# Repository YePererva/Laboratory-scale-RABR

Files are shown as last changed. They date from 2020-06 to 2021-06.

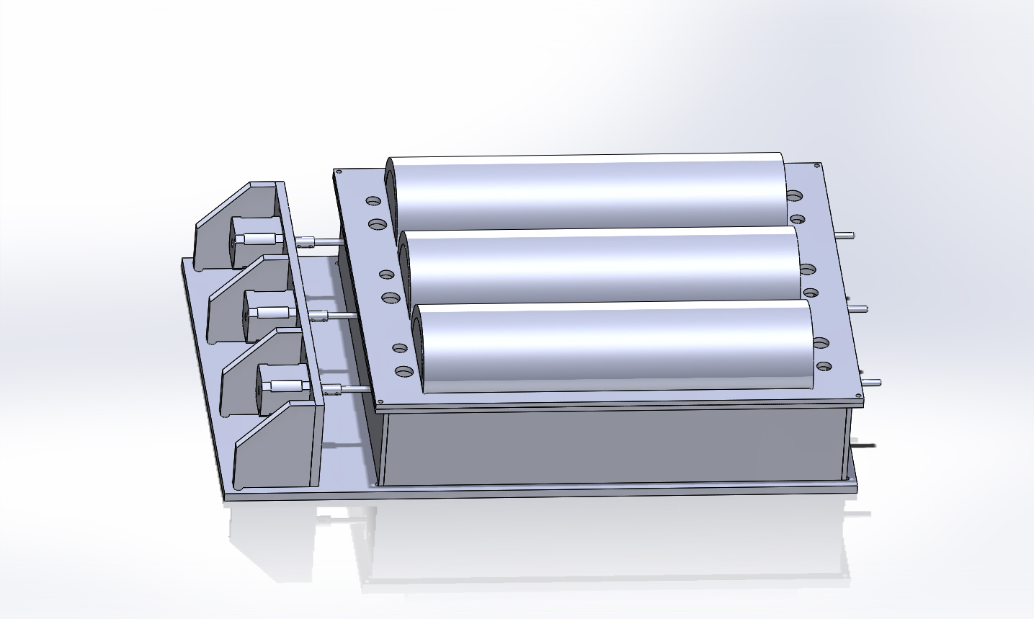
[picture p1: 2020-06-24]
images/RABR_Covered.JPG

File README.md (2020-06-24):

# Laboratory scale RABR

This repository contains some developments on laboratory-scale Rotating Algal Biofilm Reactor (RABR).
The reactor were build for one of student-projects.

# Content

Folder `electronics` contains the schematics for two designed devices:
- Motor controller for there stepper motors as shaft drives for reactor
- Environment monitor for monitoring conditions of air and light around reactor. This monitor reads:
   - Temperature, Pressure and Relative Humidity of air (with conversion to absolute humidity)
   - Total flux, Photo-synthetically Active Radiation, UV flux.

Folder `models` contains the designer reactor for running in triplicate.

Folder `images` contains CAD renders and photos taken of working reactor and equipment.

# Used tools:
- KiCad : for schematics
- SolidWorks Educational : for designing the reactor

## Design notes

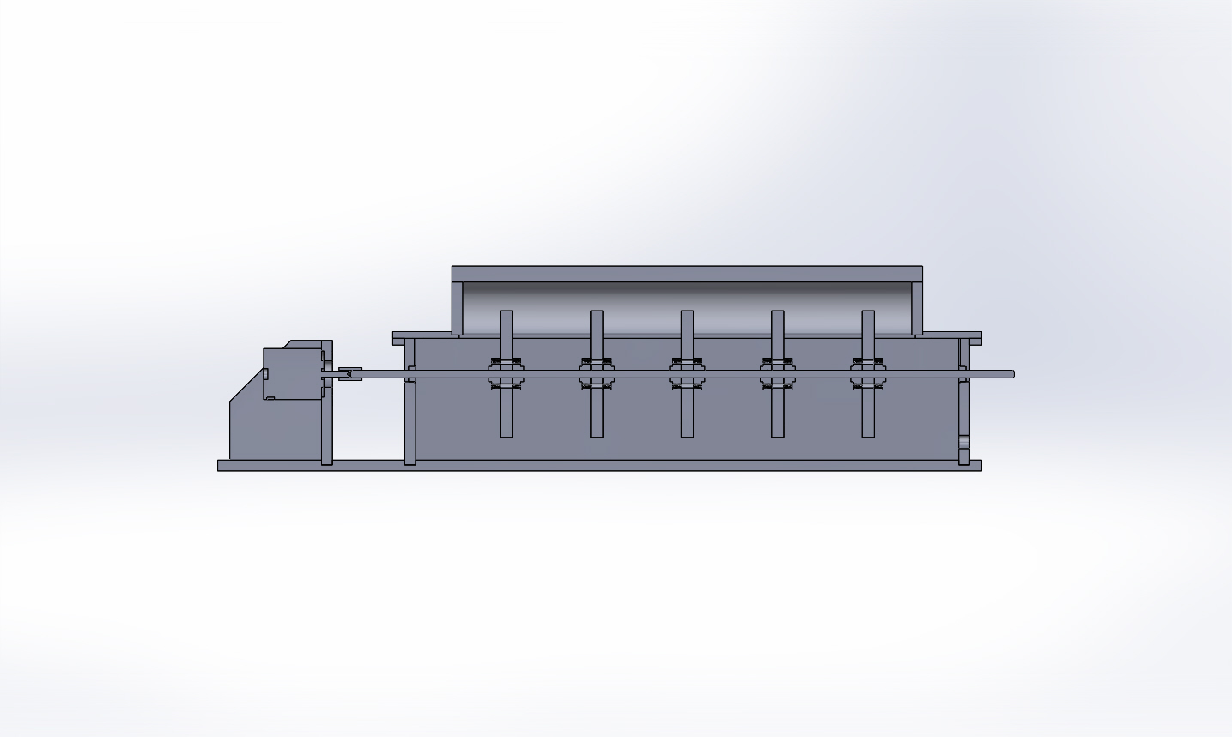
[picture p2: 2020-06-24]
images/RABR_Covered_.JPG

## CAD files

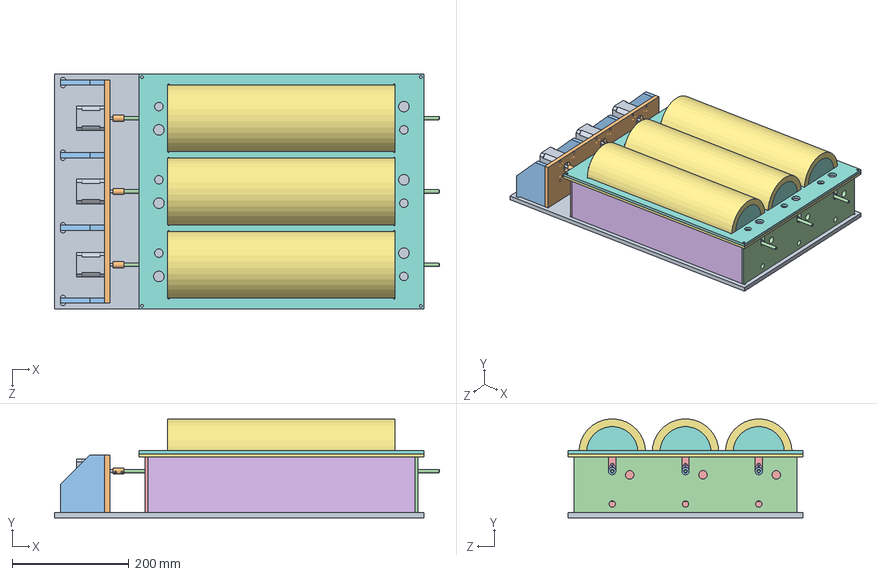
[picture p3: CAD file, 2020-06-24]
models/RABR_Covered.SLDASM
660.0 x 169.7 x 402.4 mm
bottom_plate^RABR_Covered
motor_plate^RABR_Covered
back_support^RABR_Covered x 4
outer_shaft_support^RABR_Covered
inner_shaft_support^RABR_Covered
separator^RABR_Covered x 4
bottom_lid^RABR_Covered
top_lid^RABR_Covered
NEMA17 x 3
Shaft_Coupler x 3
Bearing_immitation x 6
Shaft^RABR_Covered x 3
disk^RABR_Covered x 15
shaft_moun_hub x 30
Cover^RABR_Covered x 3
cover_side^RABR_Covered x 6

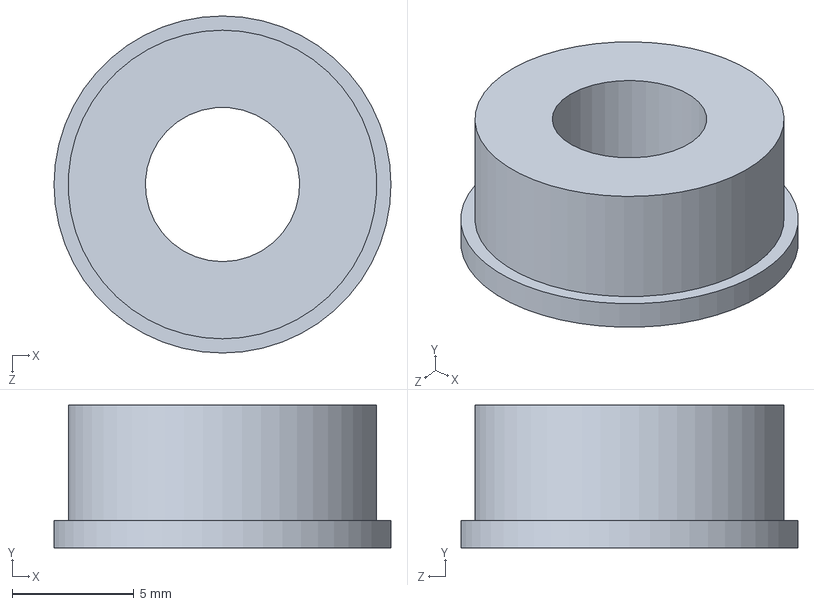
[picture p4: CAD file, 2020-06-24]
models/external_parts/Bearing_immitation.SLDPRT
13.9 x 5.87 x 13.9 mm

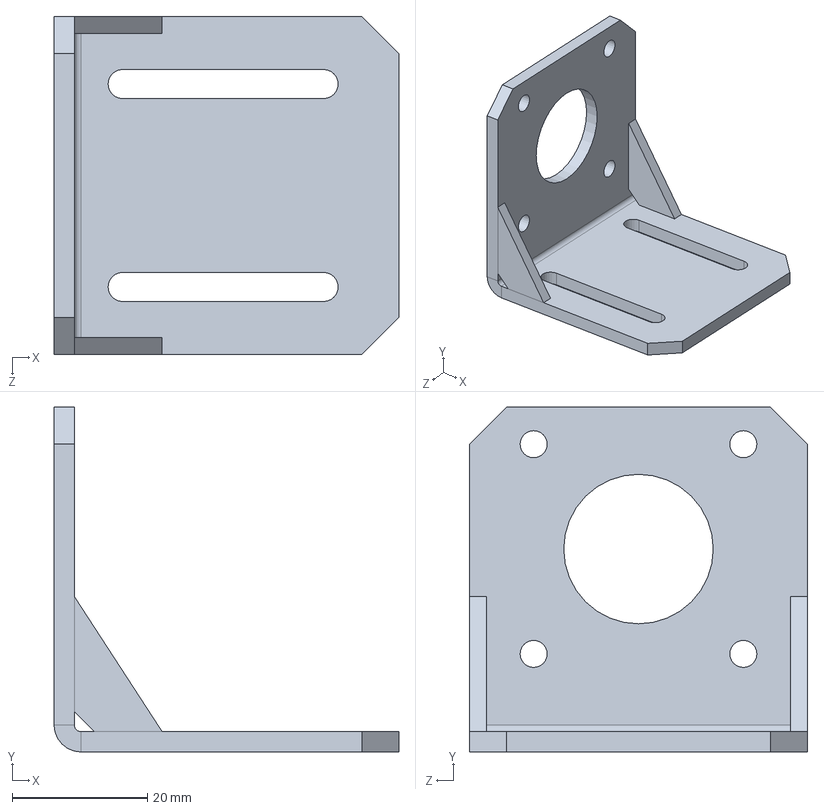
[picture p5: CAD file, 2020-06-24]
models/external_parts/NEMA17_Adaptor.SLDPRT
51.0 x 51.0 x 50.0 mm

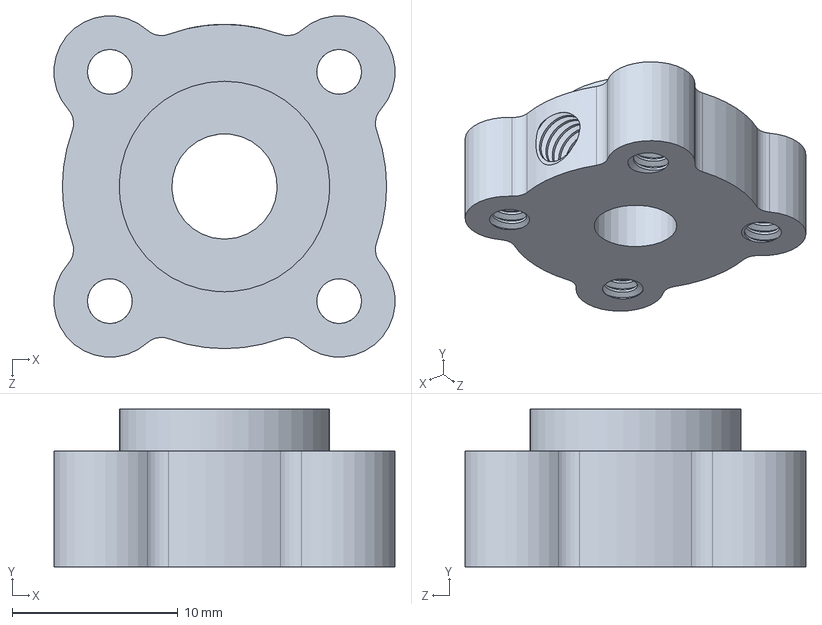
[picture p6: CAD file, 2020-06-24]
models/external_parts/shaft_moun_hub.SLDPRT
20.6 x 9.53 x 20.6 mm

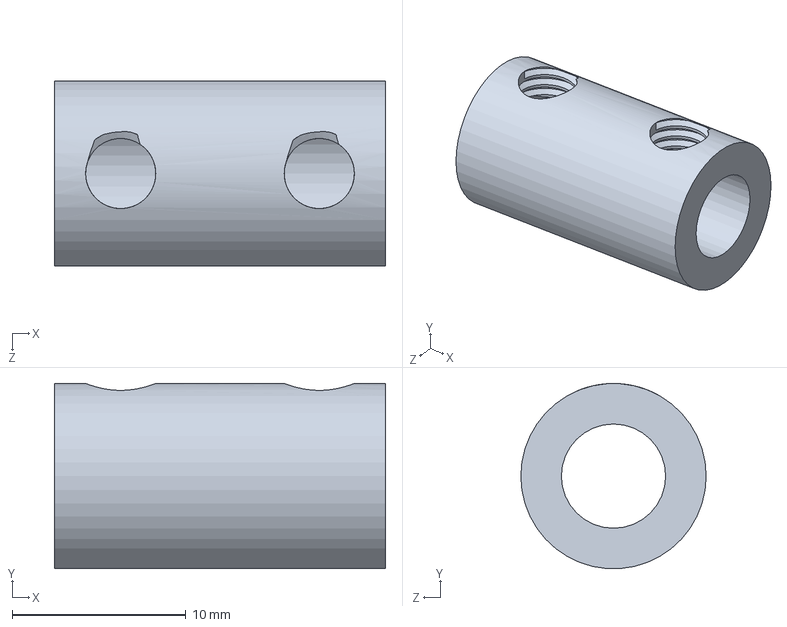
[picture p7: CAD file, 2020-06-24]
models/external_parts/Shaft_Coupler.SLDPRT
19.1 x 10.7 x 10.7 mm

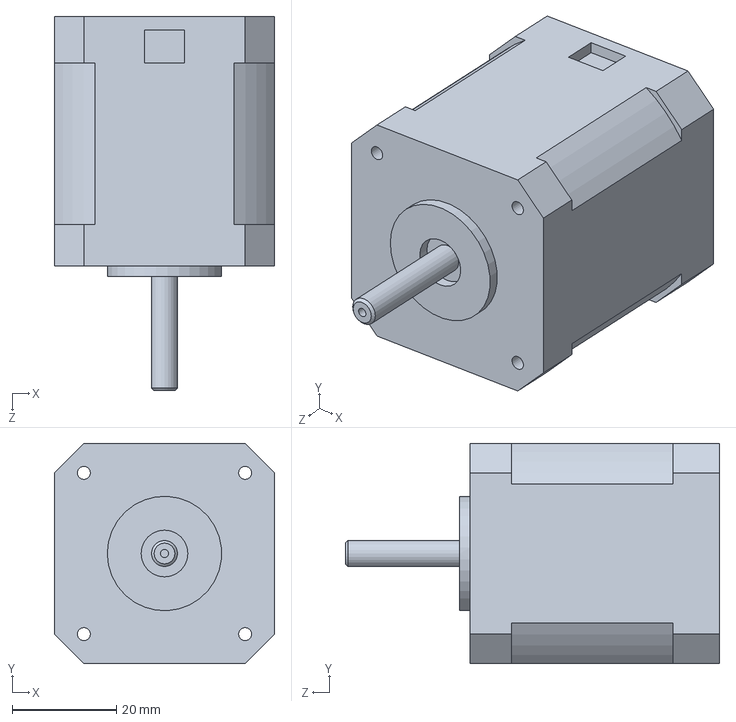
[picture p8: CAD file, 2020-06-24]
models/external_parts/NEMA17.SLDPRT
42.3 x 42.3 x 72.0 mm

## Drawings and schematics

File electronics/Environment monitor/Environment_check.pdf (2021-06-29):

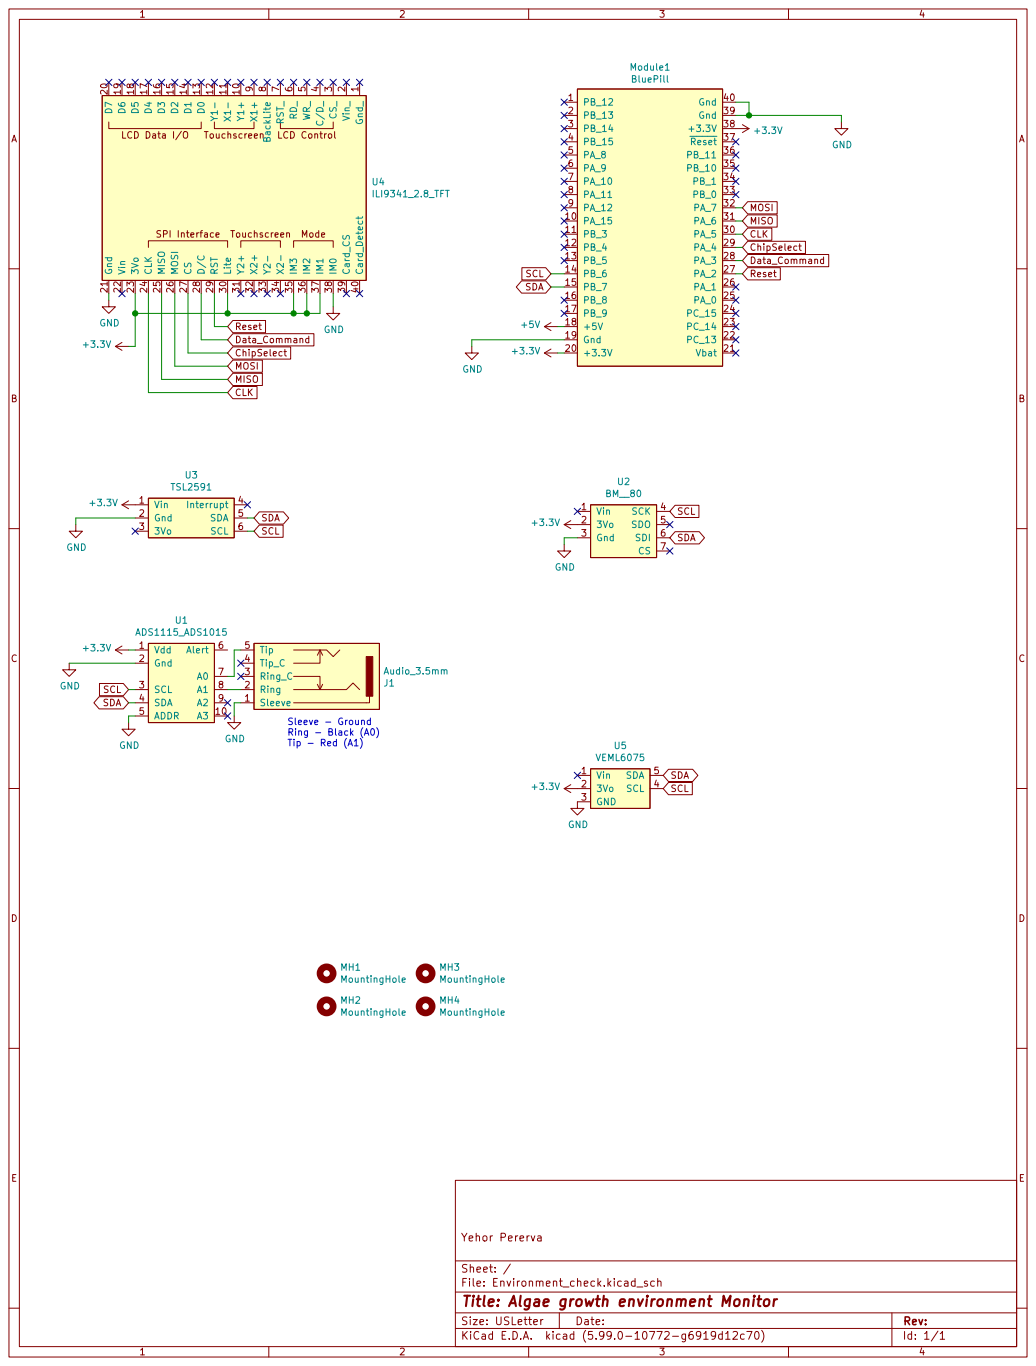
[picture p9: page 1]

2 D7 20 Gnd 21 Vin 22 3Vo 23 CLK 24 MISO 25 MOSI 26 CS 27 D/C 28 RST 29 CS_

CLK ChipSelect Data_Command MOSI Reset Sleeve - Ground Ring - Black (A0)

File: Environment_check.kicad_sch Sheet: / Yehor Pererva

Id: 1/1 Title: Algae growth environment Monitor

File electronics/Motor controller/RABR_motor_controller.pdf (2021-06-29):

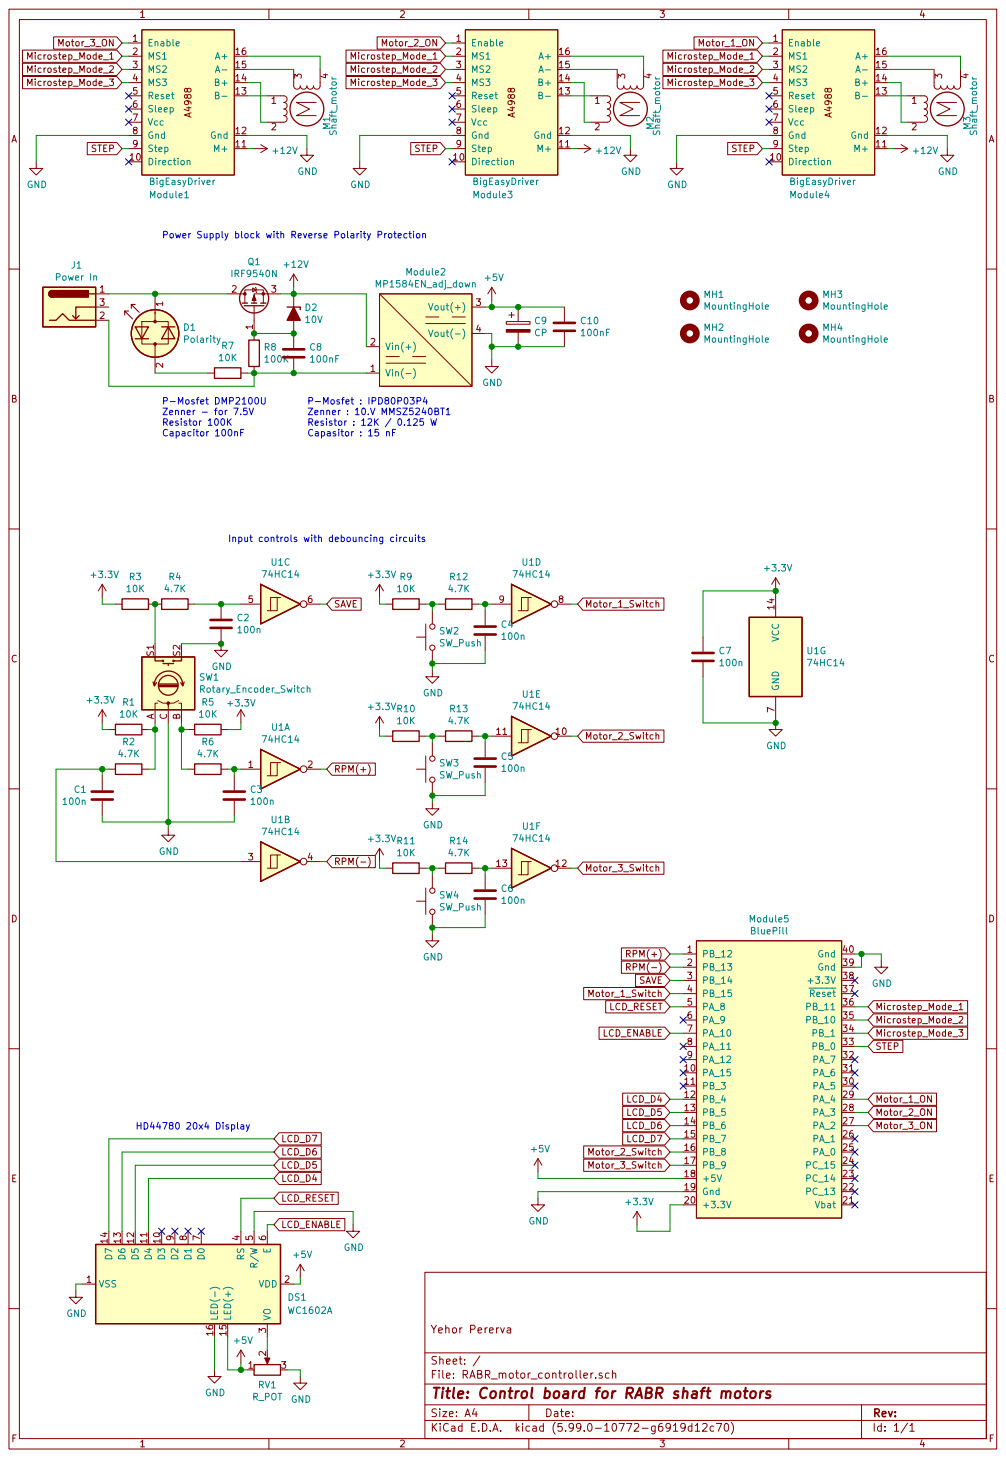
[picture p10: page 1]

4 M2 Shaft_motor A4988 Enable 1 Direction 10 M+ 11 Gnd 12 B- 13 B+ 14 A- 15 A+ 16 MS1 2 MS2 3 MS3 4 Reset 5 Sleep 6 Vcc 7 Gnd 8 Step 9 Module4 GND BigEasyDriver +12V MH1 MountingHole MH3 MountingHole
STEP Motor_1_ON Microstep_Mode_1

Power Supply block with Reverse Polarity Protection P-Mosfet : IPD80P03P4 Zenner : 10.V MMSZ5240BT1 Resistor : 12K / 0.125 W

Capasitor : 15 nF P-Mosfet DMP2100U
Zenner - for 7.5V Resistor 100K Capacitor 100nF

Input controls with debouncing circuits

File: RABR_motor_controller.sch Sheet: / Yehor Pererva

Id: 1/1 Title: Control board for RABR shaft motors

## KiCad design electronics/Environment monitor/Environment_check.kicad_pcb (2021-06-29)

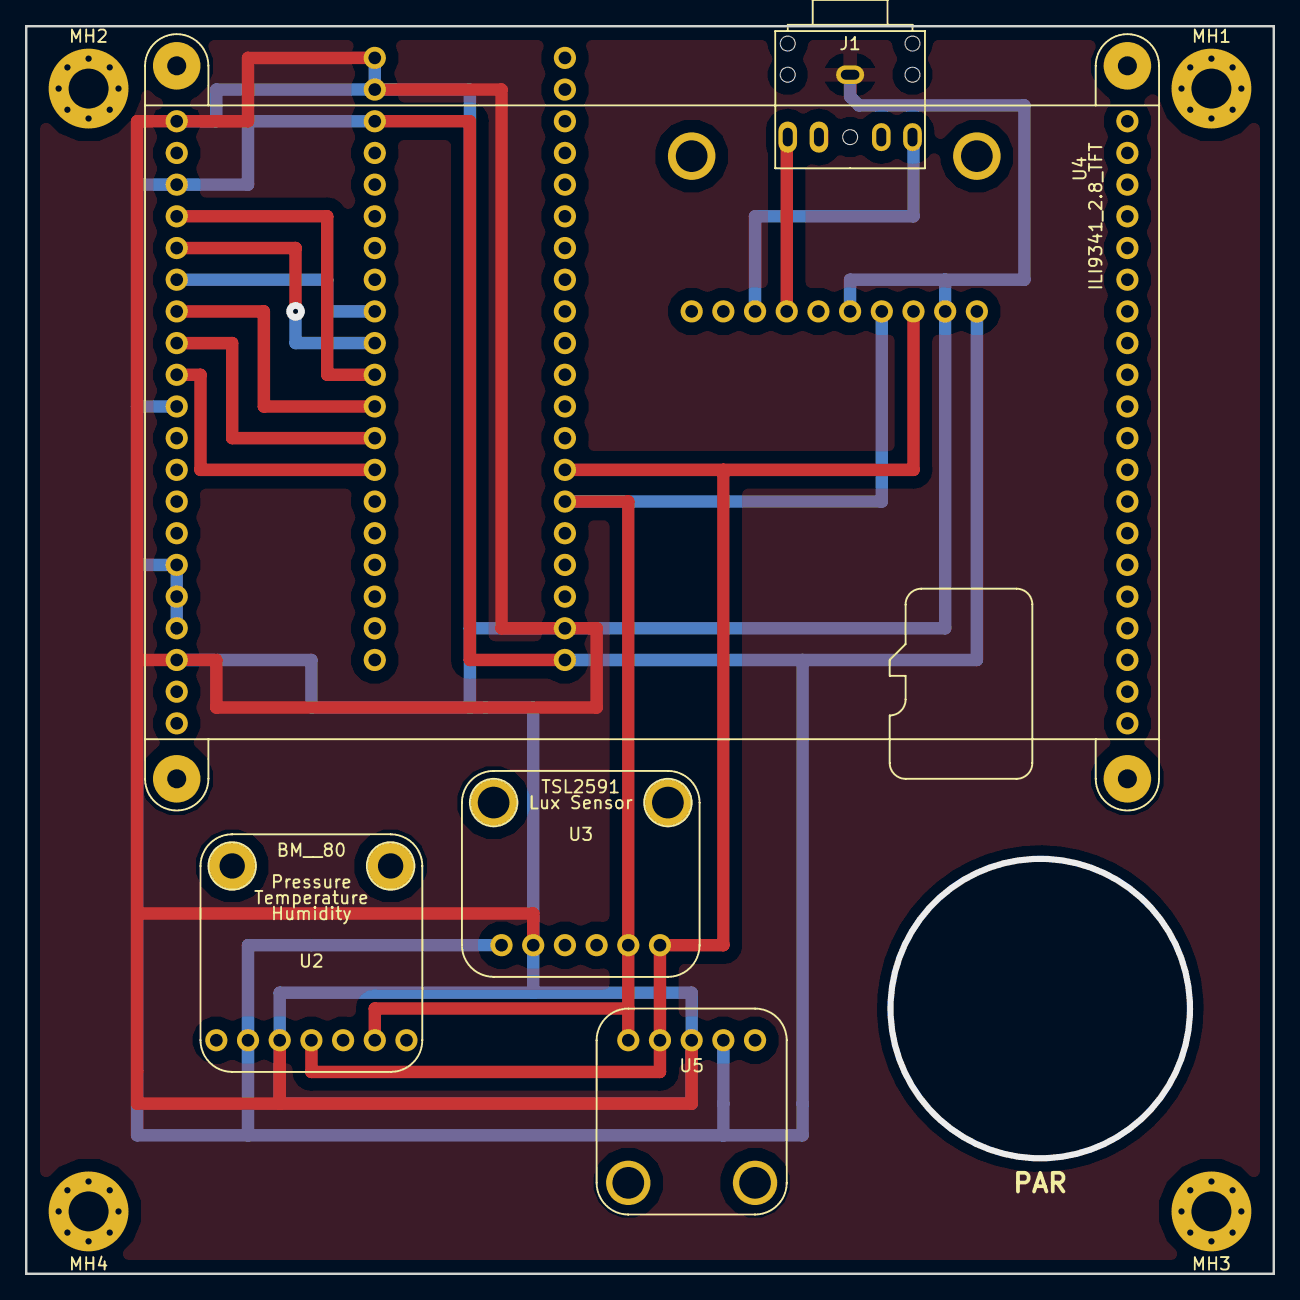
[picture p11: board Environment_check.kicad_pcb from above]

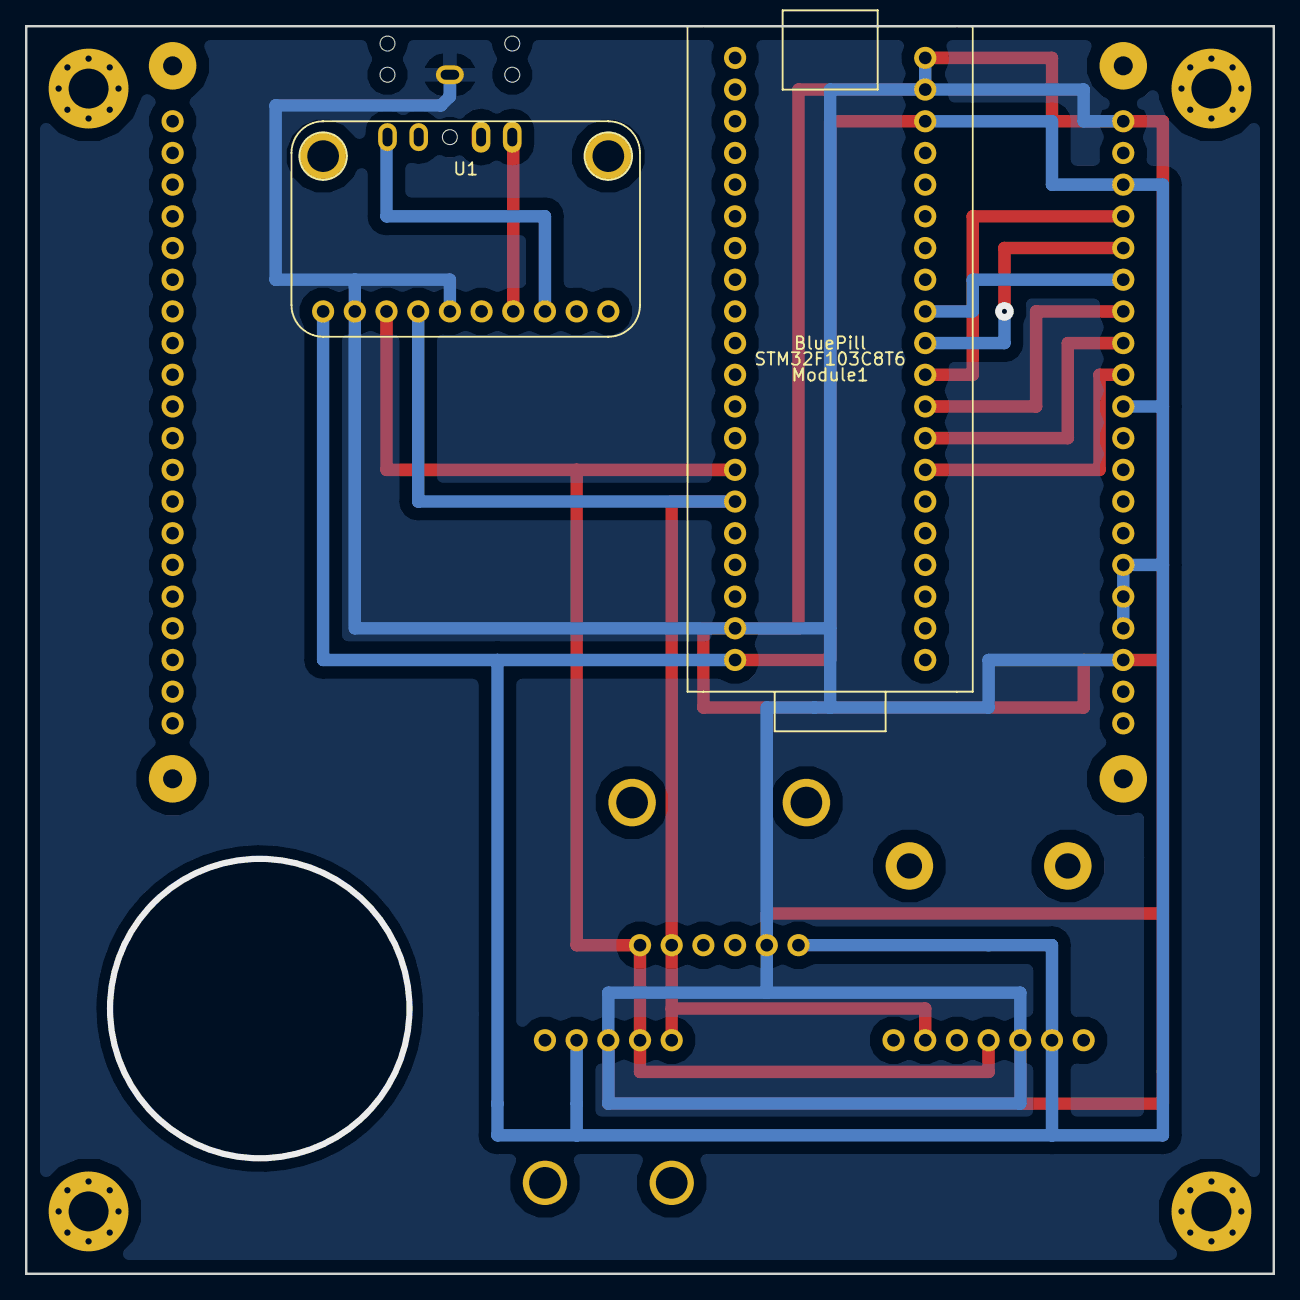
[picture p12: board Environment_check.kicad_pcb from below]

Board: 2 copper layers, 100.0 x 100.0 mm, 11 parts (2 on the bottom side), 12 nets.

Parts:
J1: Audio_3.5mm; Audio 3.5 Jack [4Ucon 08780]
MH1, MH2, MH3, MH4: MountingHole; MountingHole_3.2mm_M3_Pad_Via
Module1: BluePill
U1: ADS1115_ADS1015
U2: BM__80; BME280_BMP280_BME680
U3: TSL2591
U4: ILI9341_2.8_TFT; adafruit_ILI9341_2.8_double_mode
U5: VEML6075

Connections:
+3V3: Module1.20, Module1.38, U1.1, U2.2, U3.1, U4.23, U4.30, U4.35, U4.36, U4.37, U5.2
CLK: Module1.30, U4.24
ChipSelect: Module1.29, U4.27
Data_Command: Module1.28, U4.28
GND: J1.1, Module1.19, Module1.39, Module1.40, U1.2, U1.5, U2.3, U3.2, U4.21, U4.38, U5.3
MISO: Module1.31, U4.25
MOSI: Module1.32, U4.26
unnamed: J1.2, U1.8
unnamed: J1.5, U1.7
Reset: Module1.27, U4.29
SCL: Module1.14, U1.3, U2.4, U3.6, U5.4
SDA: Module1.15, U1.4, U2.6, U3.5, U5.5

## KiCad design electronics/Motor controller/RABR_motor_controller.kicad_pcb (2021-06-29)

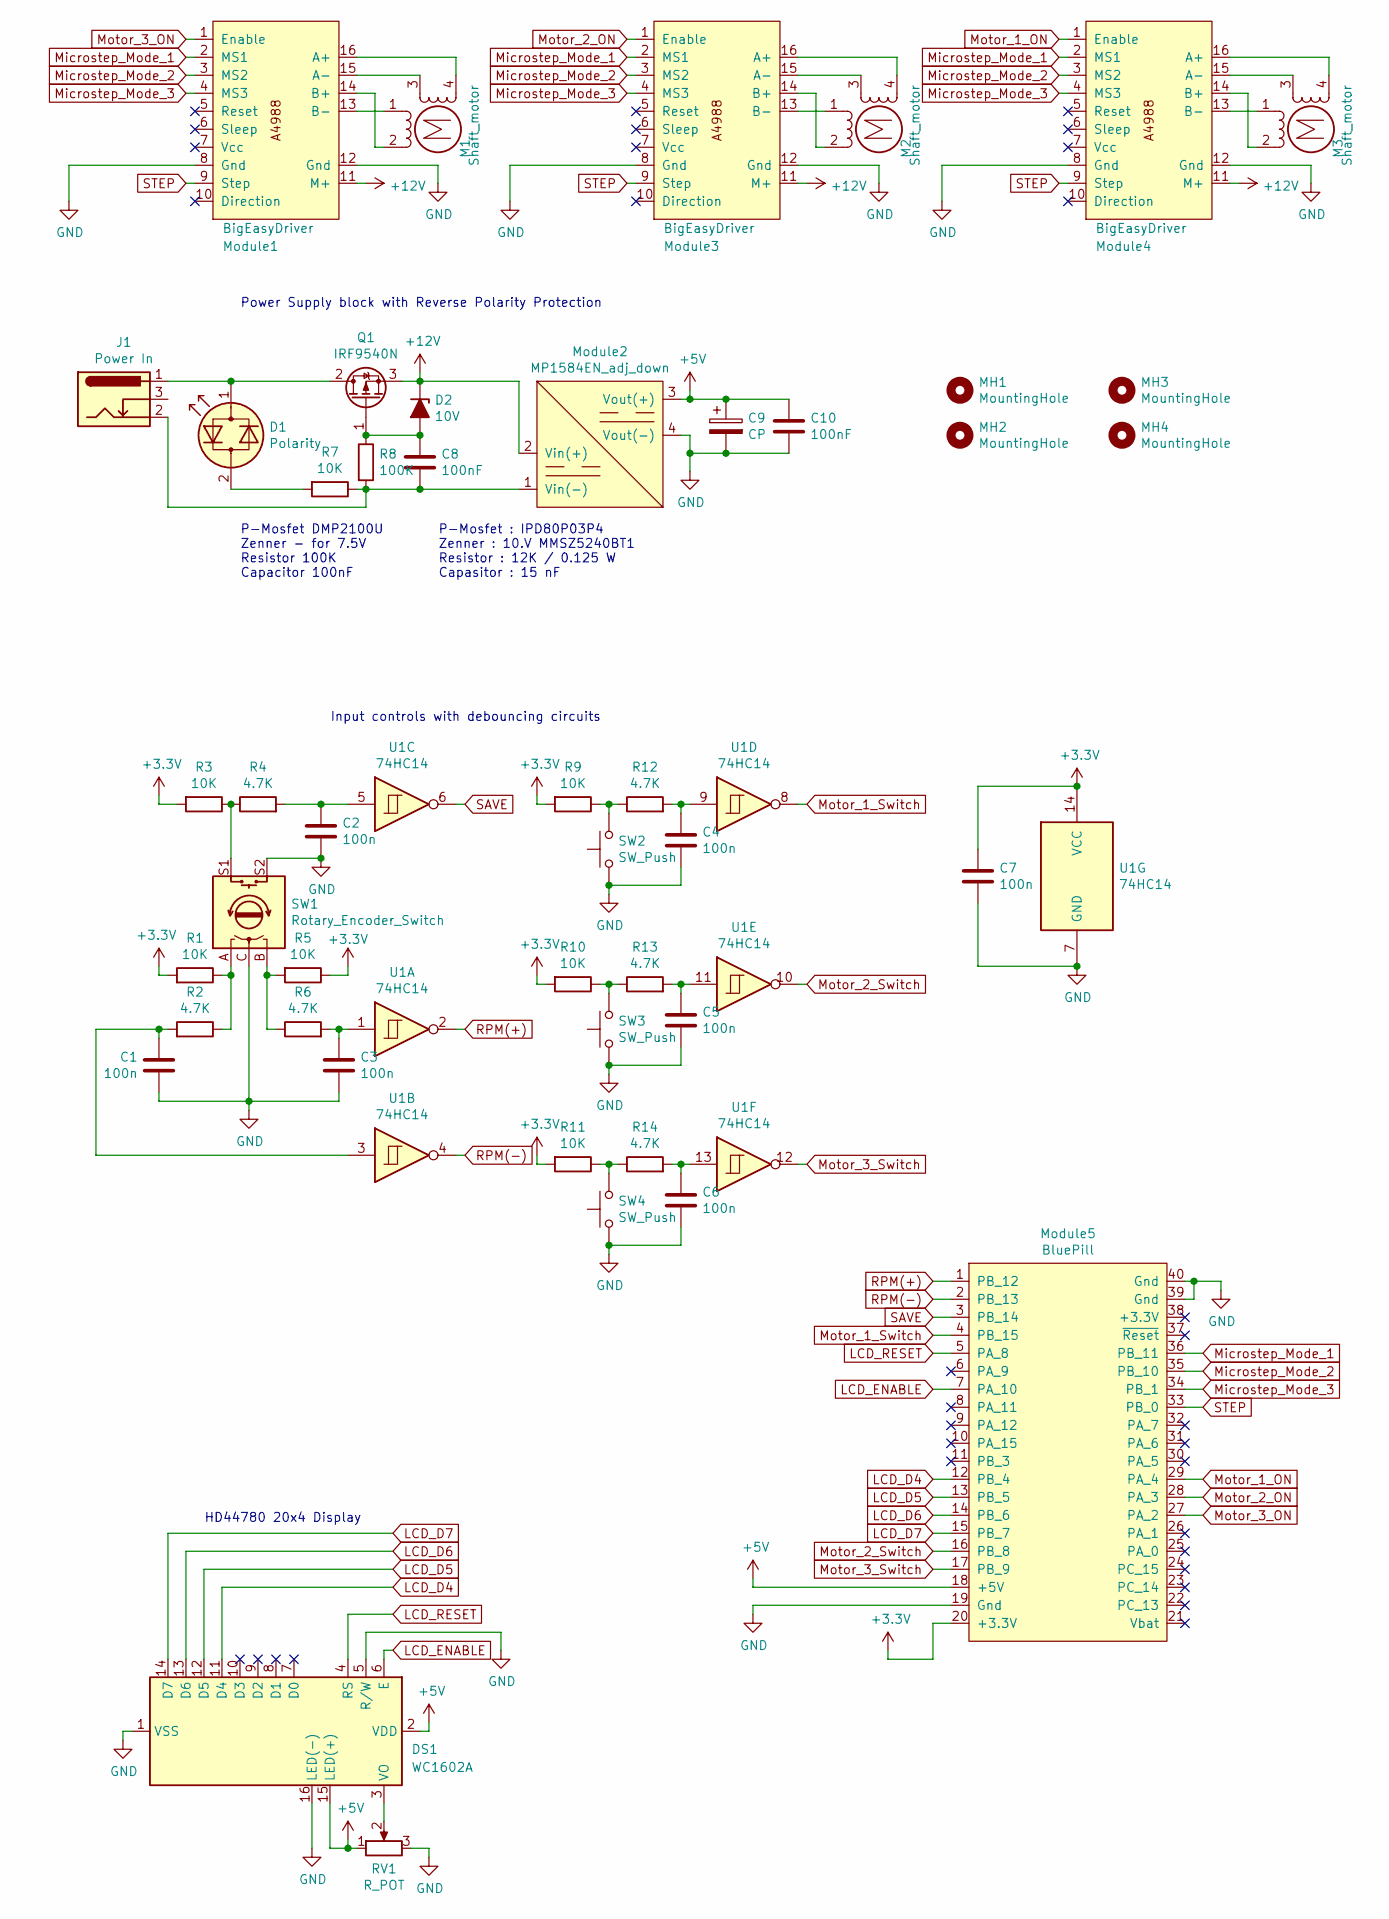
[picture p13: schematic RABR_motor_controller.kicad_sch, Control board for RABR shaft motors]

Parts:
C1, C2, C3, C4, C5, C6, C7: 100n; C_0805_2012Metric_Pad1.15x1.40mm_HandSolder
C8, C10: 100nF; C_0805_2012Metric_Pad1.15x1.40mm_HandSolder
C9: CP; CP_Elec_10x10
D1: Polarity; LED_D3.0mm_Clear
D2: 10V; D_DO-41_SOD81_P7.62mm_Horizontal
DS1: WC1602A
J1: Power In; BarrelJack_Horizontal
M1, M2, M3: Shaft_motor; TerminalBlock_Phoenix_MPT-0,5-4-2.54_1x04_P2.54mm_Horizontal
MH1, MH2, MH3, MH4: MountingHole; MountingHole_3.2mm_M3_DIN965_Pad
Module1, Module3, Module4: BigEasyDriver; BigEasyDriver_v1.6
Module2: MP1584EN_adj_down; MP1584_adj
Module5: BluePill
Q1: IRF9540N; TO-220-3_Vertical
R1, R3, R5, R7, R9, R10, R11: 10K; R_1206_3216Metric_Pad1.42x1.75mm_HandSolder
R2, R4, R6, R12, R13, R14: 4.7K; R_1206_3216Metric_Pad1.42x1.75mm_HandSolder
R8: 100K; R_1206_3216Metric_Pad1.42x1.75mm_HandSolder
RV1: R_POT; Potentiometer_Bourns_3386C_Horizontal
SW1: Rotary_Encoder_Switch; RotaryEncoder_Alps_EC12E-Switch_Vertical_H20mm
SW2, SW3, SW4: SW_Push; SW_PUSH_6mm_H8.5mm
U1: 74HC14; DIP-14_W7.62mm_LongPads

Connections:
+3V3: C7.1, Module5.20 (+3.3V), R1.2, R3.2, R5.1, R9.2, R10.2, R11.2, U1.14 (VCC)
+5V: C9.1, C10.1, DS1.2 (VDD), DS1.15 (LED(+)), Module2.3 (Vout(+)), Module5.18 (+5V), RV1.1
+12V: D2.1 (K), Module1.11 (M+), Module2.2 (Vin(+)), Module3.11 (M+), Module4.11 (M+), Q1.3 (S)
GND: C1.2, C2.2, C3.2, C4.2, C5.2, C6.2, C7.2, C9.2, C10.2, DS1.1 (VSS), DS1.5 (R/W), DS1.16 (LED(-)), Module1.8 (Gnd), Module1.12 (Gnd), Module2.4 (Vout(-)), Module3.8 (Gnd), Module3.12 (Gnd), Module4.8 (Gnd), Module4.12 (Gnd), Module5.19 (Gnd), Module5.39 (Gnd), Module5.40 (Gnd), RV1.3, SW1.C, SW1.S2, SW2.1, SW3.1, SW4.1, U1.7 (GND)
LCD_D4: DS1.11 (D4), Module5.12 (PB_4)
LCD_D5: DS1.12 (D5), Module5.13 (PB_5)
LCD_D6: DS1.13 (D6), Module5.14 (PB_6)
LCD_D7: DS1.14 (D7), Module5.15 (PB_7)
LCD_ENABLE: DS1.6 (E), Module5.7 (PA_10)
LCD_RESET: DS1.4 (RS), Module5.5 (PA_8)
Microstep_Mode_1: Module1.2 (MS1), Module3.2 (MS1), Module4.2 (MS1), Module5.36 (PB_11)
Microstep_Mode_2: Module1.3 (MS2), Module3.3 (MS2), Module4.3 (MS2), Module5.35 (PB_10)
Microstep_Mode_3: Module1.4 (MS3), Module3.4 (MS3), Module4.4 (MS3), Module5.34 (PB_1)
Motor_1_ON: Module4.1 (Enable), Module5.29 (PA_4)
Motor_1_Switch: Module5.4 (PB_15), U1.8
Motor_2_ON: Module3.1 (Enable), Module5.28 (PA_3)
Motor_2_Switch: Module5.16 (PB_8), U1.10
Motor_3_ON: Module1.1 (Enable), Module5.27 (PA_2)
Motor_3_Switch: Module5.17 (PB_9), U1.12
unnamed: C1.1, R2.2, U1.3
unnamed: C2.1, R4.2, U1.5
unnamed: C3.1, R6.2, U1.1
unnamed: C4.1, R12.2, U1.9
unnamed: C5.1, R13.2, U1.11
unnamed: C6.1, R14.2, U1.13
unnamed: C8.1, D2.2 (A), Q1.1 (G), R8.1
unnamed: C8.2, J1.2, Module2.1 (Vin(-)), R7.1, R8.2
unnamed: D1.1 (KA), J1.1, Q1.2 (D)
unnamed: D1.2 (AK), R7.2
unnamed: DS1.3 (VO), RV1.2
unnamed: M1.1, Module1.13 (B-)
unnamed: M1.2 (-), Module1.14 (B+)
unnamed: M1.3, Module1.15 (A-)
unnamed: M1.4, Module1.16 (A+)
unnamed: M2.1, Module3.13 (B-)
unnamed: M2.2 (-), Module3.14 (B+)
unnamed: M2.3, Module3.15 (A-)
unnamed: M2.4, Module3.16 (A+)
unnamed: M3.1, Module4.13 (B-)
unnamed: M3.2 (-), Module4.14 (B+)
unnamed: M3.3, Module4.15 (A-)
unnamed: M3.4, Module4.16 (A+)
unnamed: R1.1, R2.1, SW1.A
unnamed: R3.1, R4.1, SW1.S1
unnamed: R5.2, R6.1, SW1.B
unnamed: R10.1, R13.1, SW3.2
unnamed: R11.1, R14.1, SW4.2
unnamed: R9.1, R12.1, SW2.2
RPM(+): Module5.1 (PB_12), U1.2
RPM(-): Module5.2 (PB_13), U1.4
SAVE: Module5.3 (PB_14), U1.6
STEP: Module1.9 (Step), Module3.9 (Step), Module4.9 (Step), Module5.33 (PB_0)

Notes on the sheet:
HD44780 20x4 Display
Power Supply block with Reverse Polarity Protection
P-Mosfet DMP2100U Zenner - for 7.5V Resistor 100K Capacitor 100nF
Input controls with debouncing circuits
P-Mosfet : IPD80P03P4 Zenner : 10.V MMSZ5240BT1 Resistor : 12K / 0.125 W Capasitor : 15 nF

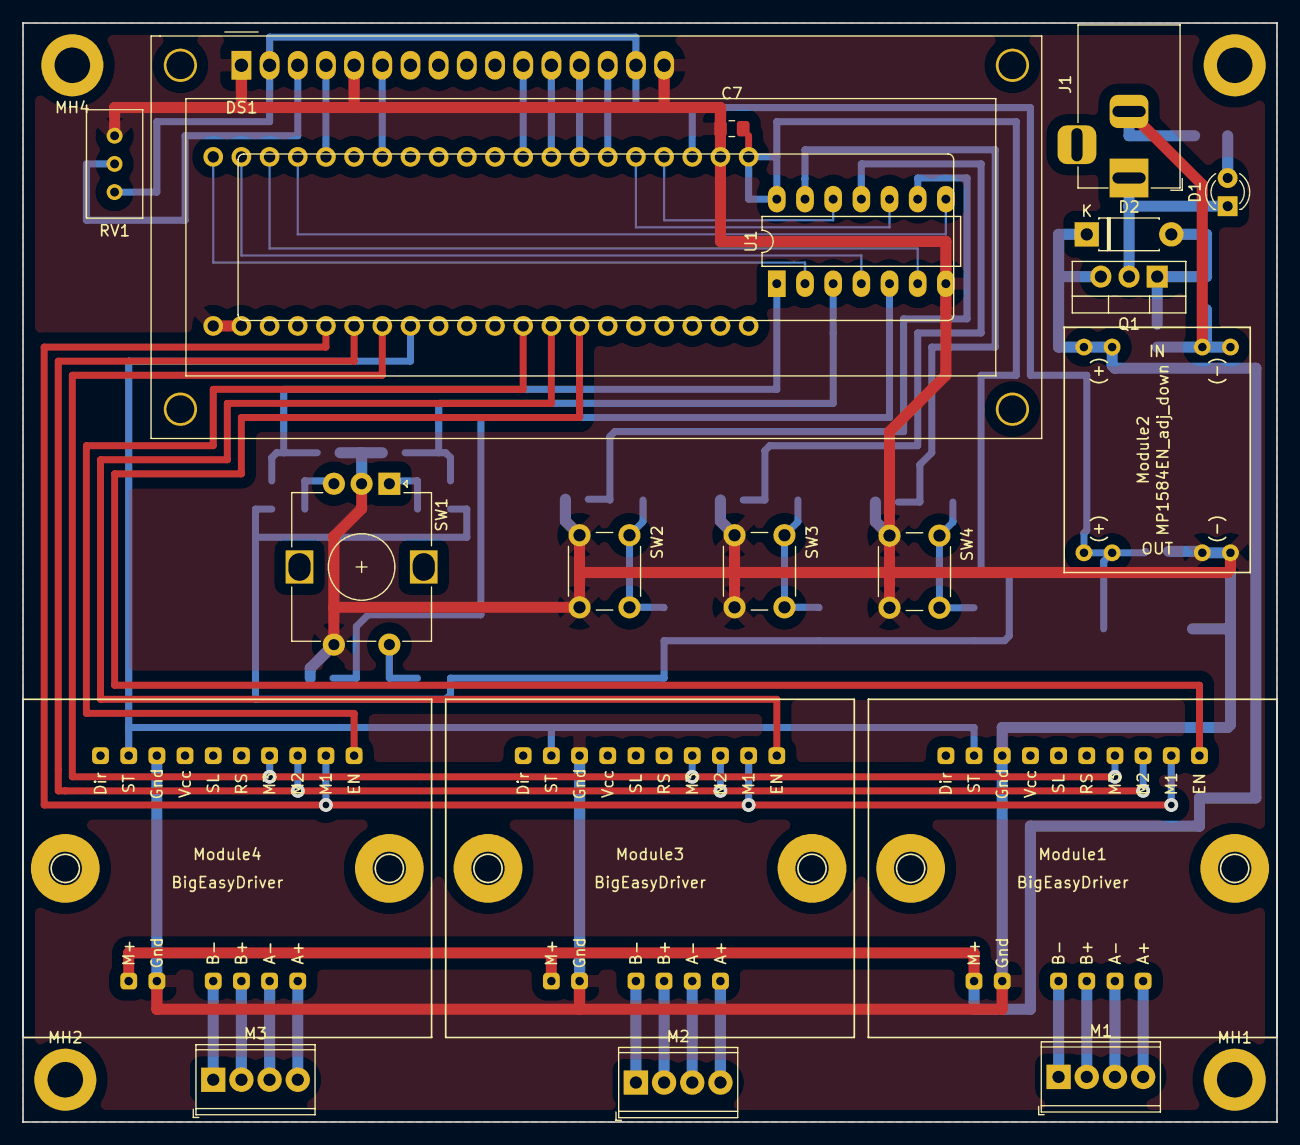
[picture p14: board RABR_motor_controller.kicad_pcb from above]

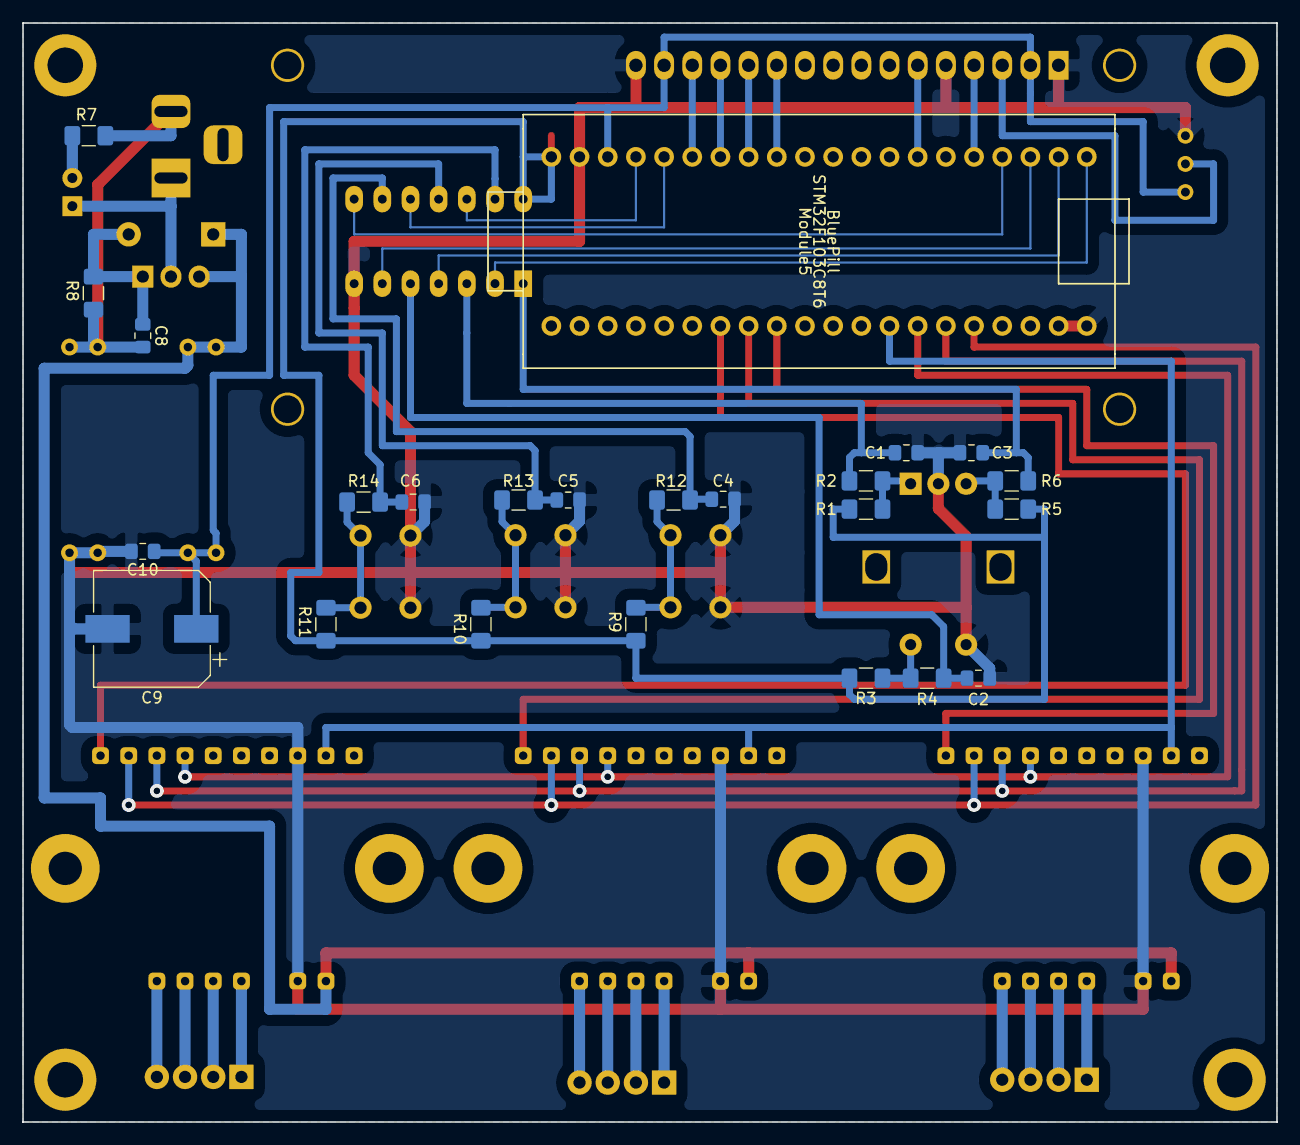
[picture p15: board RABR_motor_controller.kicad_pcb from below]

Board: 2 copper layers, 113.0 x 99.1 mm, 47 parts (24 on the bottom side), 52 nets.

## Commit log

2020-06-24 Main commit
    added main components:
    - schematics
    - models
    [Bearing_immitation.SLDPRT, Environment_check.kicad_pcb, Environment_check.sch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]
2021-06-29 Reopened with Kicad 5.99
    [Environment_check.kicad_pcb, Environment_check.kicad_sch, Environment_check.sch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]
